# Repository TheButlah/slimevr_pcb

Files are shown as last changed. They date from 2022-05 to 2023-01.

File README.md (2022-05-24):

# slimevr_pcb
A collection of PCBs designed for SlimeVR full-body trackers

- [ferrous_slime](/hardware/ferrous_slime/) - A fully custom surface-mount PCB.
  Unlike most of the SlimeVR community, it uses the ESP32-C3, a newer and more
  powerful chip. Designed to be a more powerful development platform, as it natively
  supports JTAG debugging over USB, more compilers and languages, including Rust,
  and supports Bluetooth LE v5.0.
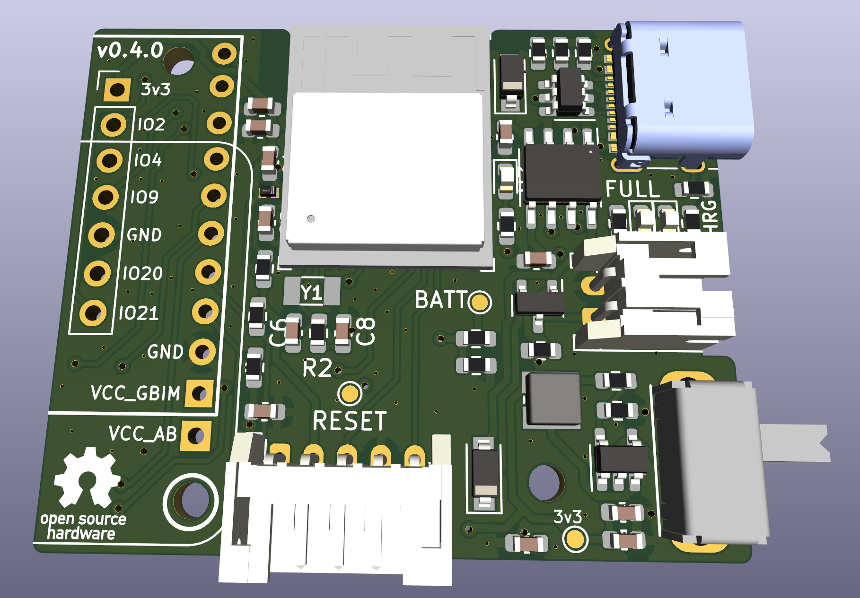
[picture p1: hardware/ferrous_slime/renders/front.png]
3d render
  
- [breakout_slime](/hardware/breakout_slime/) - A through-hole PCB for use with
  breakout boards. Simplest and easy to assemble by hand, but not as small of a
  form factor as it could be.
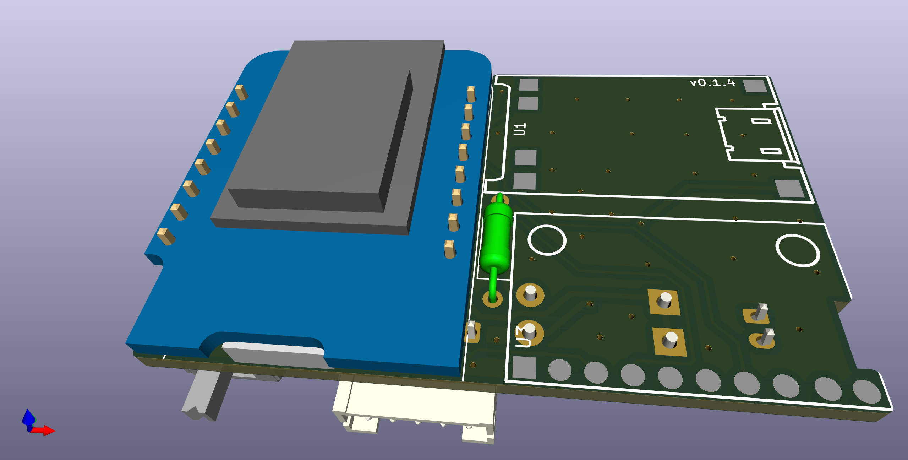
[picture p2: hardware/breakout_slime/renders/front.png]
3d render
  

## License
**This hardware is licensed under the CERN-OHL-P v2 license**, which is a permissive,
non-viral and non-reciprocal open hardware license. Unlike software licenses like
MIT and Apache 2.0, it better handles the nuances of hardware and protects both
the licensor and licensee from patent lawsuits.

**Unless you explicitly state otherwise, any contribution intentionally submitted
for inclusion in this work by you, shall be licensed as above, without any
additional terms or conditions.**

### Conveying notice of License
Note that as part of the CERN-OHL-P v2 license, recipients of manufactured
hardware must also receive notice of the above license. One such
method of conveying the notice is to include a link to the original source repo,
or printing "Licensed under CERN-OHL-P v2" on the PCB silkscreen. For more info,
see [here](https://ohwr.org/project/cernohl/wikis/uploads/8a6b5d01f71c207c49493e4d114d61e6/cern_ohl_p_v2_howto.pdf).

This is conceptually similar to the MIT/Apache 2.0 Licenses, where the original
license must still be included as a notice even when the source is modified and
subsequently relicensed under different terms.

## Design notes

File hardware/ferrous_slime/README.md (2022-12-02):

# Ferrous SlimeVR
This PCB design is intended as a production-ready (mostly) SMT design. Unlike
current SlimeVR designs by the community and the production batch that use the
ESP8266, this board uses the *very* new ESP32-C3 chip, which is better in almost
all respects than its predecessors.

The IMU is still a breakout board to better allow the community to experiment
with different IMU options.

## IMU Compatibility
This board was designed to work with the following IMU breakouts, via solder
jumpers that can reconfigure the board.
- BNO08X (Aliexpress GY-BNO08X and Adafruit BNO08X)
- MPU-6050 (Aliexpress GY-521)
- MPU-9250/6500 (Aliexpress GY-9250 and MPU-92/65)
- ICM20948 3.3v (Aliexpress GY-912 and Pimoroni PIM448)

## Renders
Front
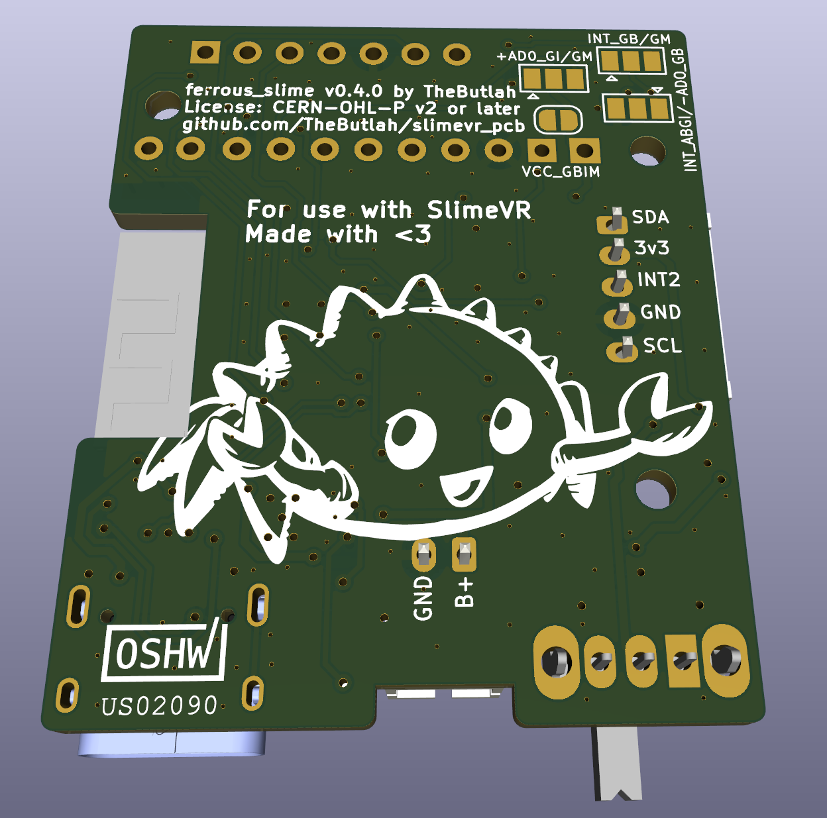
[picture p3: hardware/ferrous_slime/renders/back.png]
Back

Schematic
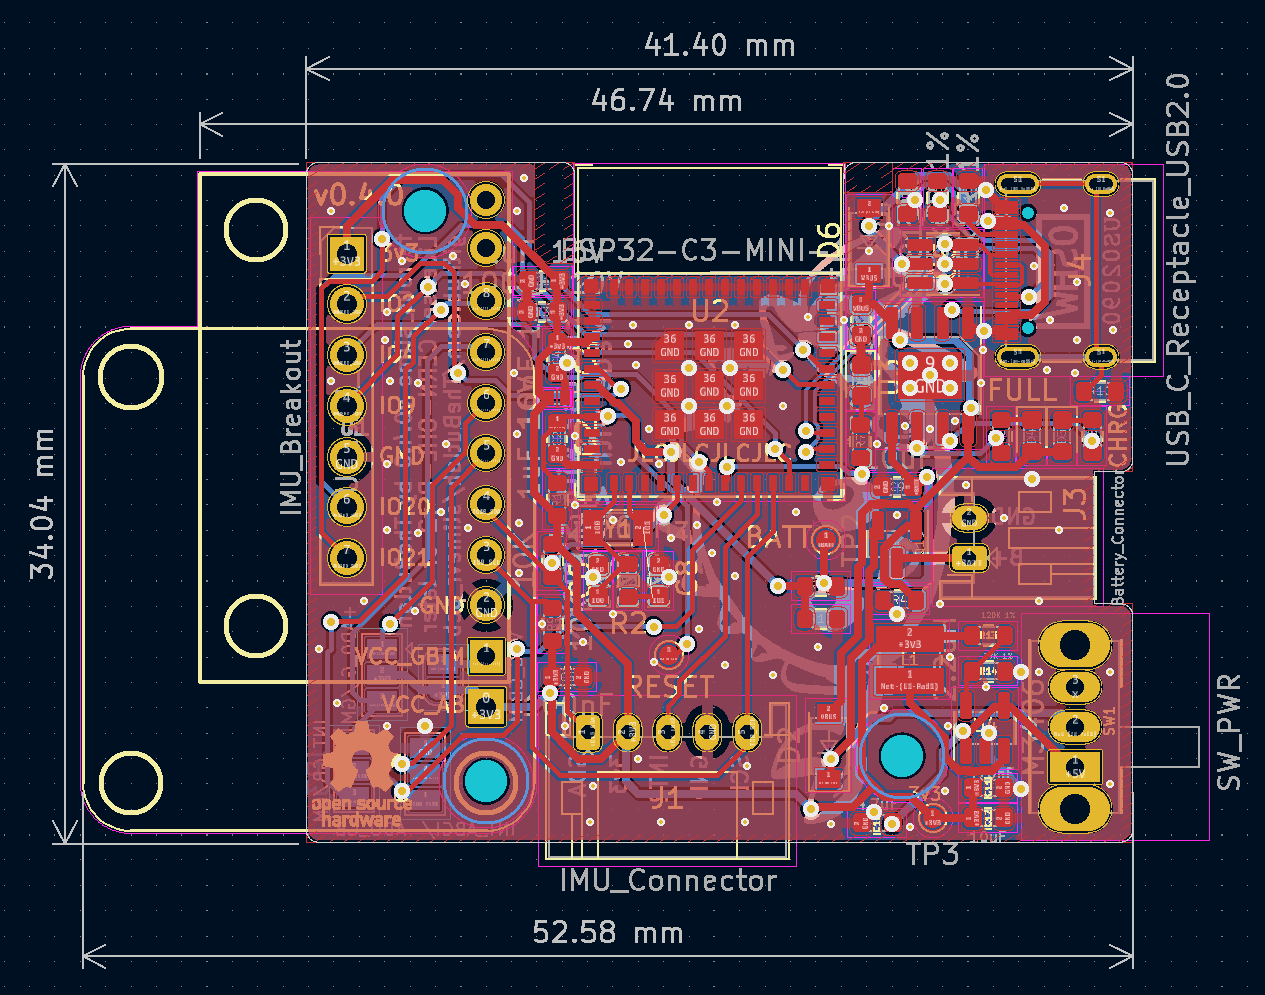
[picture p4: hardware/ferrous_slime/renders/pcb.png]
PCB


As always, check to make sure your particular breakout board has the pins in the
right spots for this PCB! Not all breakouts of the same IMU have the same pins!

## Why the ESP32-C3?
First and foremost, the ESP32-C3 uses RISC-V as its instruction set, rather than
XTensa. XTensa is not supported by LLVM (yet), or by the Rust programming language,
without using a [fork of the compiler](https://github.com/espressif/llvm-project).
I wanted to use this design in future IOT projects as well, so targeting a more
mainstream instruction set with better compiler support seems useful. It will also
help me more easily use Rust with this device!

Secondly, the ESP32-C3 is similar in features to the ESP32 series of chips, but like
the ESP8266, it is very cheap, making it a great choice. A few of the features it has
over the ESP8266:
- Bluetooth LE v5.0 (even ESP32 only has v4.2)
- Stronger WiFi signal at a lower power usage than the ESP8266
- More RAM (400KiB vs 160)
- Built-in USB-serial and USB-JTAG support eliminates need for USB-UART chip
- JTAG debugging
- Sleep modes consume *significantly* less power
- New peripherals like security modules
- GPIO is more fully featured, and has more pins

For more info, [this](https://hackaday.com/2021/02/08/hands-on-the-risc-v-esp32-c3-will-be-your-new-esp8266/)
was a good article.

## Changelog
A description of the changes in each revision can be found [here](CHANGELOG.md).

## Credits
The original v0.1.0 design was based on the schematics of the [esp-rs Rust board](https://github.com/esp-rs/esp-rust-board).
Thanks to the esp-rs community for being so awesome!
Also, thanks to the SlimeVR developers and especially @Eirenliel for making SlimeVR awesome and open source :)

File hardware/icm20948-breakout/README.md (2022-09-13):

# ICM-20948 Breakout for `ferrous_slime`
This is a breakout board for the [ICM-20948](https://invensense.tdk.com/products/motion-tracking/9-axis/icm-20948/) IMU, targeting the [`ferrous_slime` board by TheButlah](https://github.com/TheButlah/slimevr_pcb/tree/main/hardware/ferrous_slime).  It contains a voltage translator to allow 1.8v<->3.3v communication between the IMU and the ESP.

The pin socket is optional and only serves to allow rapid prototyping of the board.  Final revisions may be directly soldered to the `ferrous_slime` or attached via a double-sided pin header.

*Note: This breakout is currently being tested and may not work as intended.*

## Renders
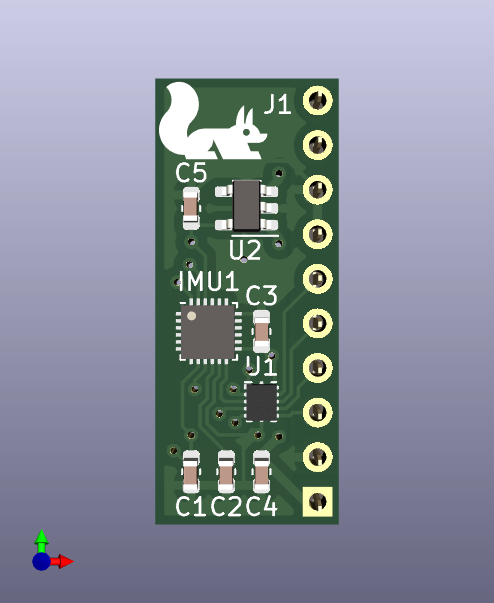
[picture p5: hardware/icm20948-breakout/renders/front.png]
Front

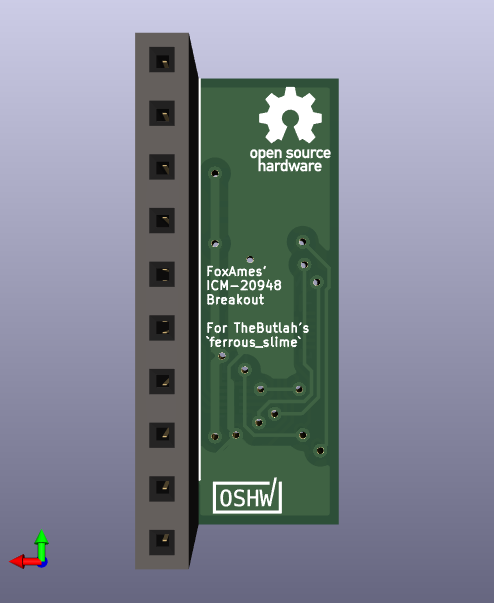
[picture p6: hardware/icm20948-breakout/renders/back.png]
Back

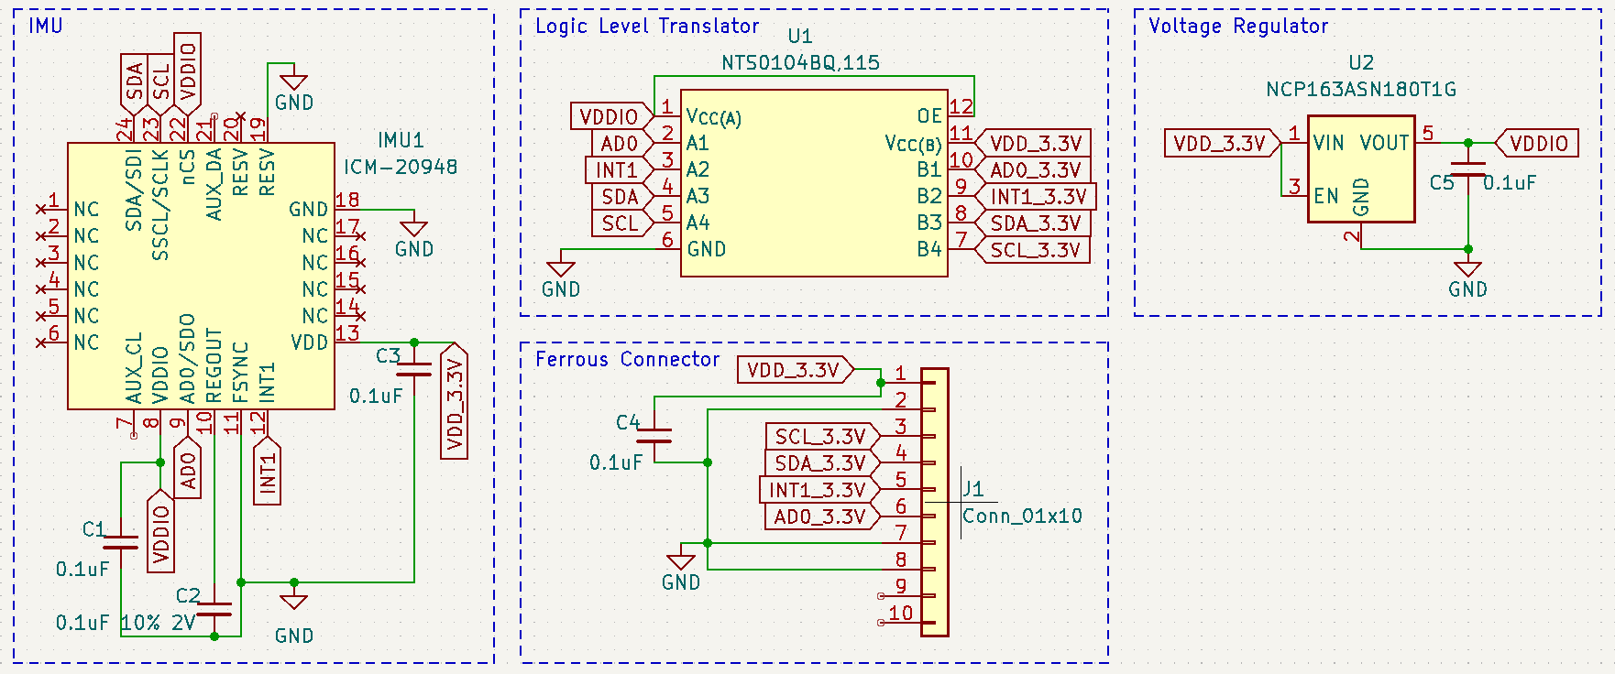
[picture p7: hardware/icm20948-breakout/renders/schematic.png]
Schematic


## Thanks
- [dtornqvist](https://github.com/dtornqvist/icm-20948-breakout) for a part list and implementation reference

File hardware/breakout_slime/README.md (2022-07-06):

# Breakout SlimeVR
This PCB design is intended as the easiest DIY SlimeVR pcb. It is a simple two
layer PCB, and should make assembling SlimeVR significantly easier than using a
protoboard.

**NOTE: This has only been tested on BNOs and MPUs.**
Also, use it at your own risk. I've tested it, but I accept no responsibility for it ;)

## Renders
Front
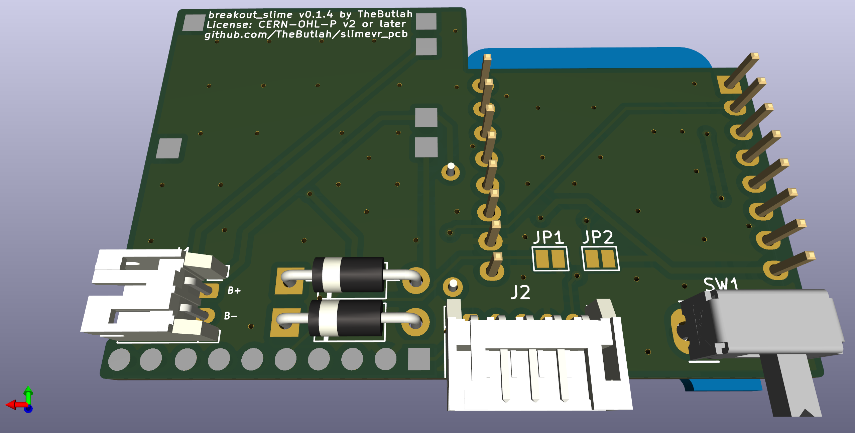
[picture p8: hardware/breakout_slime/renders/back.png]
Back

Schematic
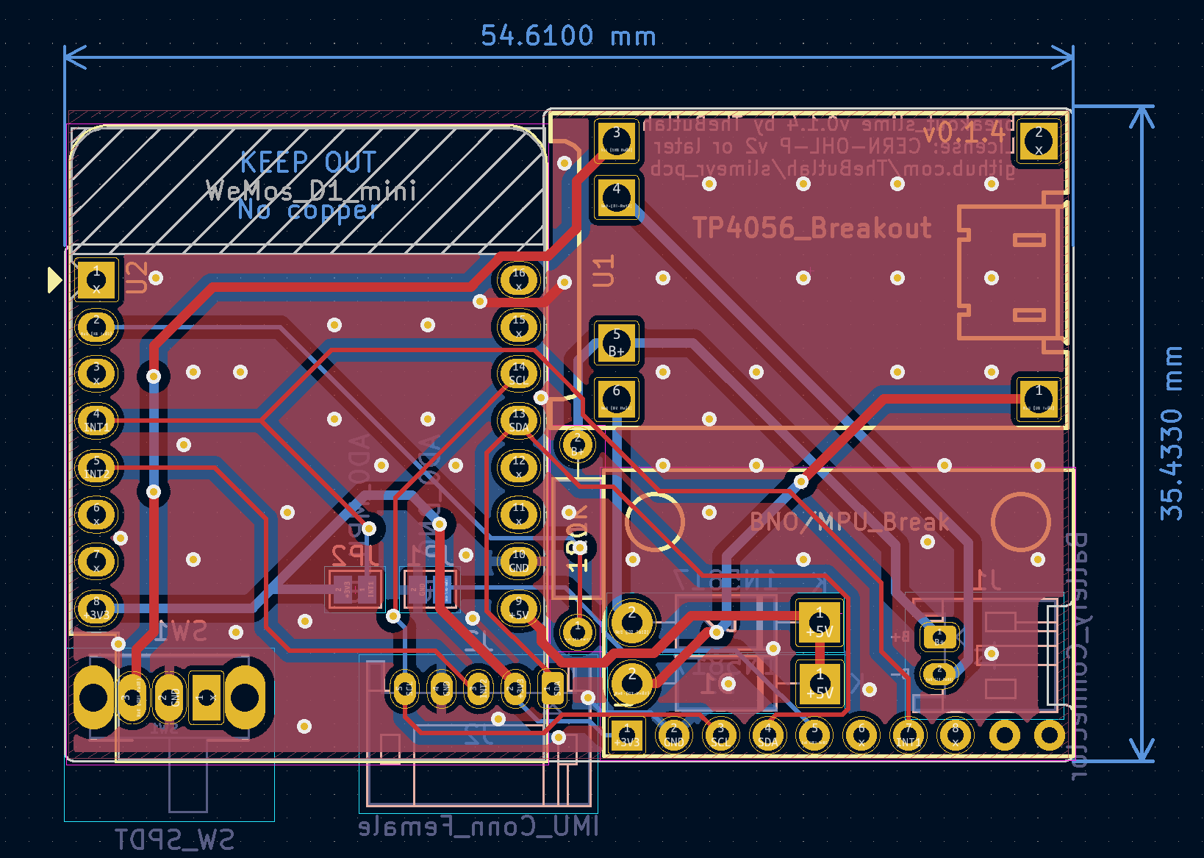
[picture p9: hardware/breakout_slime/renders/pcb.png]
PCB

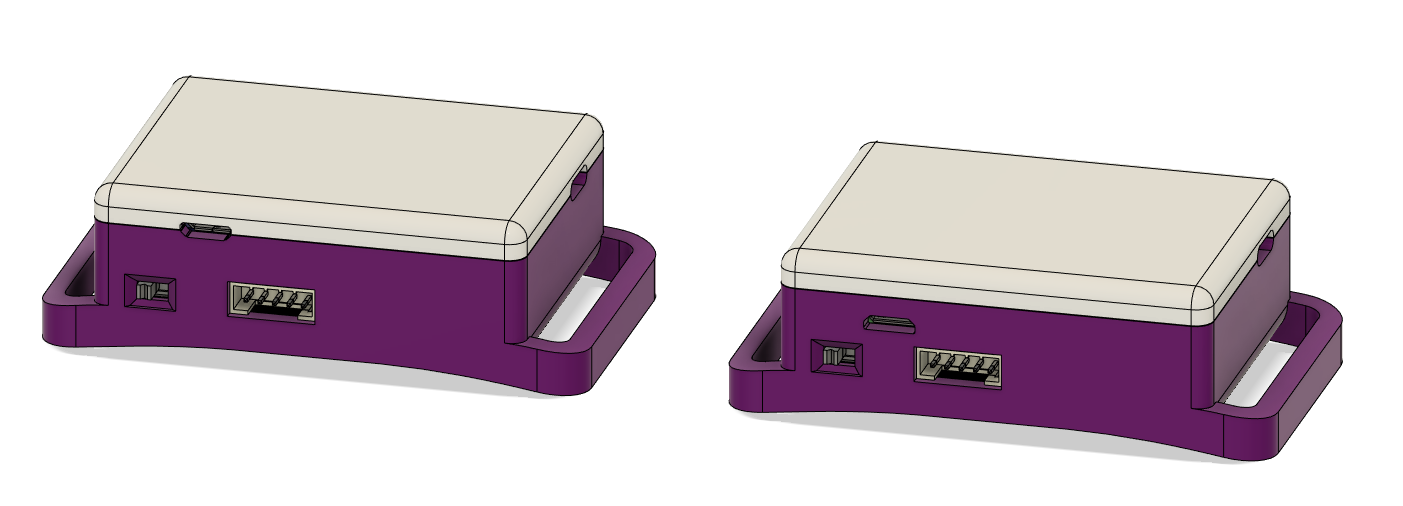
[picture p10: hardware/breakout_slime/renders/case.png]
Case


## Changelog
A description of the changes in each revision can be found [here](CHANGELOG.md).

## How to order
You can place a jlcpcb order by uploading the [zip file](jlcpcb/gerber/GERBER-breakout_slime.zip) for the gerbers. Take that zip file and upload to https://jlcpcb.com.

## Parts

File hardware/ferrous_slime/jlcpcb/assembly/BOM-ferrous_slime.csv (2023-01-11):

Comment | Designator | Footprint | LCSC
100nF 10V | C3,C5 | C_0603_1608Metric | C14663
1uF 16V | C1,C2 | C_0603_1608Metric | C15849
470nF | C11 | C_0603_1608Metric | C1623
TP4056 | U3 | HTSOP-8-1EP_3.9x4.9mm_P1.27mm_EP2.4x3.2mm | C16581
LESD8D3.3CAT5G | D1 | SOD882 | C172409
4.7uF | C10 | C_0603_1608Metric | C19666
10uF | C12,C7,C9 | C_0603_1608Metric | C19702
2.2uH | L1 | L_Wuerth_MAPI-3015 | C19734
1K | R5,R6,R7 | R_0603_1608Metric | C21190
CHRG | D3 | LED_0603_1608Metric | C2286
27K 1% | R14 | R_0603_1608Metric | C22967
2K | R3 | R_0603_1608Metric | C22975
30K 1% | R12 | R_0603_1608Metric | C22984
5k1R 1% | R15,R16 | R_0603_1608Metric | C23186
10kR 1% | R1,R8,R9 | R_0603_1608Metric | C25804
120K | R10,R11,R13,R4 | R_0603_1608Metric | C25808
ESP32-C3-MINI-1 | U2 | ESP32-C3-MINI-1 | C2838502
USB_C_Receptacle_USB2.0 | J4 | USB_C_Receptacle_XKB_U262-16XN-4BVC11 | C319148
10nF 10V | C4 | C_0603_1608Metric | C57112
LED_IO5 | D5 | LED_0603_1608Metric | C72038
FULL | D4 | LED_0603_1608Metric | C72043
M3406 | U4 | SOT-23-5 | C83224
SRV05-4 | U5 | SOT-23-6 | C85364
CJ2305 | Q1 | SOT-23 | C8549
B5819W | D2,D6 | D_SOD-123 | C8598
IMU_Connector | J1 | JST_PH_S5B-PH-K_1x05_P2.00mm_Horizontal
3v3 | TP3 | TestPoint_Pad_D1.0mm
Battery_Connector | J3 | JST_PH_S2B-PH-K_1x02_P2.00mm_Horizontal
SW_PWR | SW1 | SW_CuK_OS102011MA1QN1_SPDT_Angled
+AD0_GI/GM | JP1 | SolderJumper-3_P1.3mm_Open_Pad1.0x1.5mm
IMU_Breakout | U1 | IMU_Breakout
BATT | TP2 | TestPoint_Pad_D1.0mm
INT_GB/GM | JP3 | SolderJumper-3_P1.3mm_Open_Pad1.0x1.5mm
INT_ABGI/-ADO_GB | JP2 | SolderJumper-3_P1.3mm_Open_Pad1.0x1.5mm
DNP | R2 | R_0603_1608Metric
Unused_IO | J2 | IO_Breakouts
VCC_GBIM | JP4 | SolderJumper-2_P1.3mm_Open_RoundedPad1.0x1.5mm
RESET | TP1 | TestPoint_Pad_D1.0mm

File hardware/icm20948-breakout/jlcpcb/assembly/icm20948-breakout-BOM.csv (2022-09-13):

Comment | Designator | Footprint
NCP163ASN180T1G | U2 | SOT-23-5
0.1uF 10% 2V | C2 | C_0603_1608Metric
0.1uF | C5,C4,C1,C3 | C_0603_1608Metric
NTS0104BQ,115 | U1 | XQFN12
ICM-20948 | IMU1 | QFN-24-1EP_3x3mm_P0.4mm_EP1.75x1.6mm
Conn_01x10 | J1 | PinSocket_1x10_P2.54mm_Vertical

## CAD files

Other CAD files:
hardware/breakout_slime/case/Butter_Dish.3mf
hardware/breakout_slime/case/breakout_slime.3mf
hardware/breakout_slime/case/Butter_Dish_Fusion360.f3z
hardware/breakout_slime/case/breakout_slime.f3z

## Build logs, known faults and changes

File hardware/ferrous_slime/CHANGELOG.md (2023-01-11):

# Changelog

## v0.1.0
- Initial version of the board.
- Ordered PCB to test.

## v0.2.0
- Added 3 mounting holes.
- Added support for Adafruit BNO085.
- Improved legibility of silkscreen labels.
- Decreased sharpness of corners.
- Added support for soldering IMU breakouts flush with PCB.
- Fixed rendering of imu breakout pins.

## v0.3.0
- **Switched battery polarity** to match adafruit batteries.
- Moved silkscreen for "FULL" LED.
- Made measurement markings in mm with 2 digits of precision.
- PROG pin on TP4056 was incorrectly connected to VBUS, preventing LiPo charging.
  It is now fixed.
- Simplified name of IMU_Breakout.
- Satisfied ERC for VCC pin of aliexpress imus.
- Fixed footprint/symbols not referencing each other correctly for IMU.
- Added silkscreen labels for IMU breakout pins
- Connected TP4056 heatsink to GND

## v0.4.0
- Migrated to SRV05-04 for USB ESD, decreasing size and cost.
- Completely redesigned the board layout. Its much more efficient now, there is
  actually a large amount of unused space now.
- Removed all vias-in-pads, which was why v0.3.0 had faulty usb connection.
- Much better placement of capacitors, they now are near the pins they try to stabilize. 
- Antennas now have some keepouts on either side for a bit more signal strength.

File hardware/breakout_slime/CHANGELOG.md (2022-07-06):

# Changelog

## v0.1
- Ordered PCB to test. Tests confirmed that pcb works for MPU, but battery
  polarity reversed, and INT1 pin goes to wrong pad which breaks BNO unless INT pin
  disabled in firmware. Battery polarity was also reversed, requiring installing
  the connector in reverse.

## v0.1.1
- Filled back ground pour.
- Fixed battery polarity on JST battery connector.
- Fixed INT1 wiring.

## v0.1.2
- Added a front ground pour, and optimized the two ground pours.
- Added edge cut on D1 antenna region.
- Added keepout on d1 antenna region.
- Added edge cut on battery connector.
- Added revision number to silkscreen.

## v0.1.3
- Changed D1 mini model to not use super tall headers in 3d view.
- Added B+ and B- to silkscreen.
- Rounded out corners of edge cuts.
- Re-reversed the battery polarity. It now has B+ on pin 1 of the JST connector. This
  matches adafruit and sparkfun conventions, and also the batteries I ordered on
  aliexpress. Not all batteries follow this convention!
- Removed the redundant keepout region on antenna, since its got edge cuts now.
- Assigned the rest of the power nets to the power netclass.
- Redid the old nets to use the thicker power netclass thickness.
- Now using same switch 3d model as `ferrous_slime`.

## v0.1.4
- Moved Power switch and IMU Connector further apart to decrease the likelihood of
  collision with a D1 mini's USB connector, if that D1 mini has the connector on the
  underside of its board.

## v0.1.5
- Added Case by @TomYumVR

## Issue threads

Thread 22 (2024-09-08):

I created a case for your PCB

Gammelstulle, 2024-09-08:
Hi :)
I liked your compact design of the PCB but the case you included was not compact enough for me.
So I made one:

https://www.thingiverse.com/thing:6759053

Hope you like it. If there is something I should included in the description at thingiverse please let me know.

TheButlah, 2024-09-09:
Super awesome! Want me to link it in the README?

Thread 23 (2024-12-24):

Question on breakout jps

timbit123, 2024-12-24:
I'm trying to flash the wimos with BNO085 (slimevr one) I soldered the jp1 and jp2 and still cannot get any values on all board. I'm not sure what I'm doing wrong? thx

TheButlah, 2024-12-24:
Hey sorry, there's not enough info to help u here. Also it's been a long time so my memory is rusty. Best to ask others in the slimevr discord. You can show them the schematics from this repo

timbit123, 2024-12-24:
ok thanks, I will ask @Gammelstulle, I think he have the same configuration as me

Closed 2024-12-24.

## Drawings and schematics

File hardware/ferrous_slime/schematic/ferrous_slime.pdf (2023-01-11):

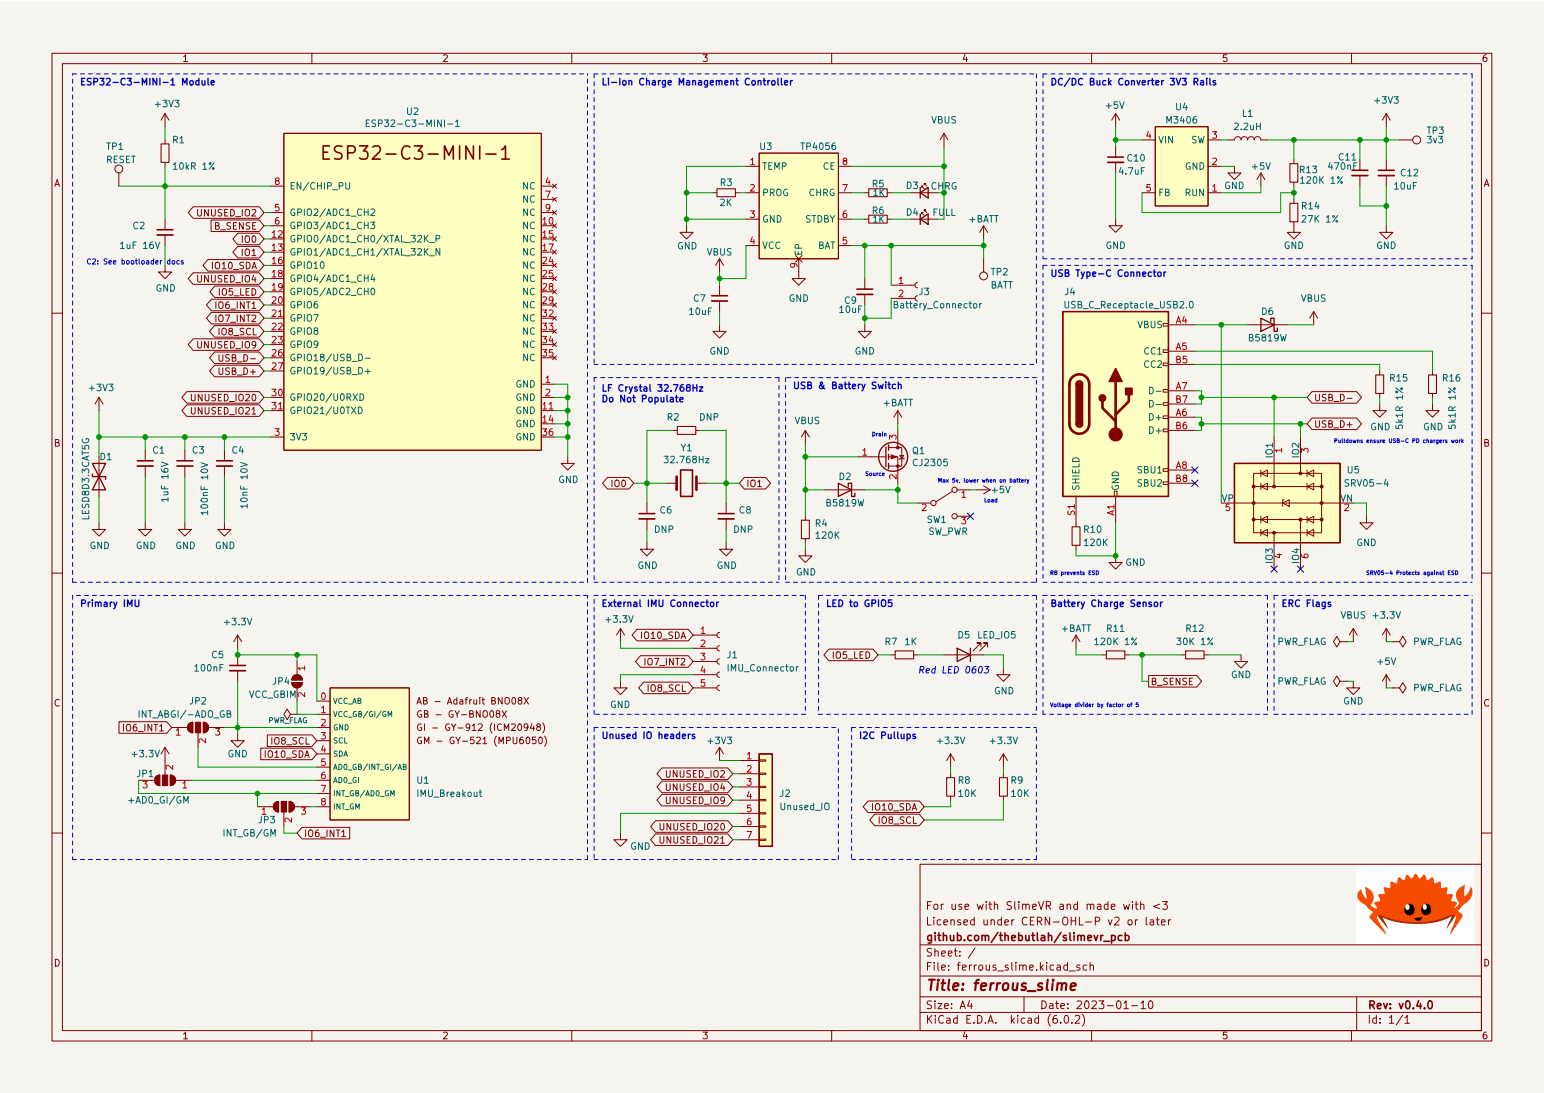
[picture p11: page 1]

DC/DC Buck Converter 3V3 Rails

Pulldowns ensure USB-C PD chargers work LF Crystal 32.768Hz
Do Not Populate

Drain Source USB & Battery Switch

R8 prevents ESD Max 5v, lower when on battery Primary IMU

Load External IMU Connector

Voltage divider by factor of 5 Battery Charge Sensor

AB - Adafruit BNO08X GB - GY-BNO08X GI - GY-912 (ICM20948)

Licensed under CERN-OHL-P v2 or later For use with SlimeVR and made with <3

File: ferrous_slime.kicad_sch Sheet: / github.com/thebutlah/slimevr_pcb

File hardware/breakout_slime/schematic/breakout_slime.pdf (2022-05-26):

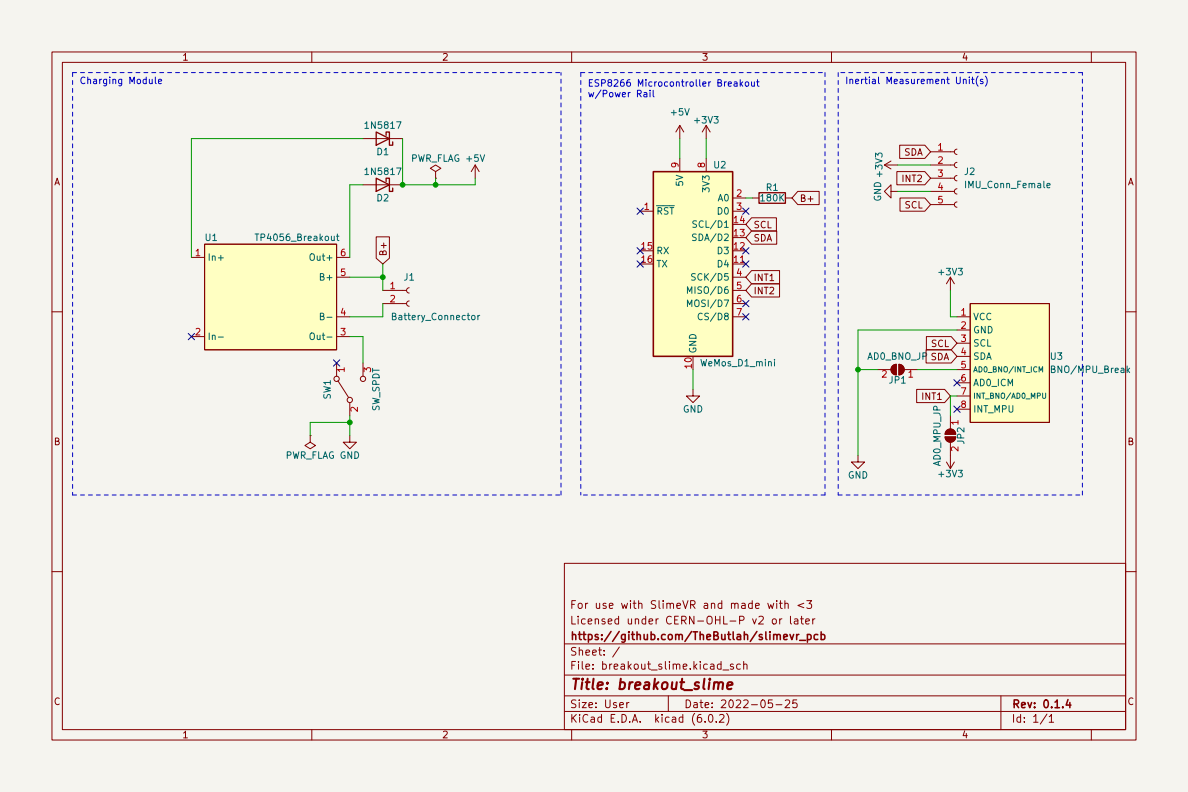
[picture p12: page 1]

File: breakout_slime.kicad_sch Sheet: / https://github.com/TheButlah/slimevr_pcb

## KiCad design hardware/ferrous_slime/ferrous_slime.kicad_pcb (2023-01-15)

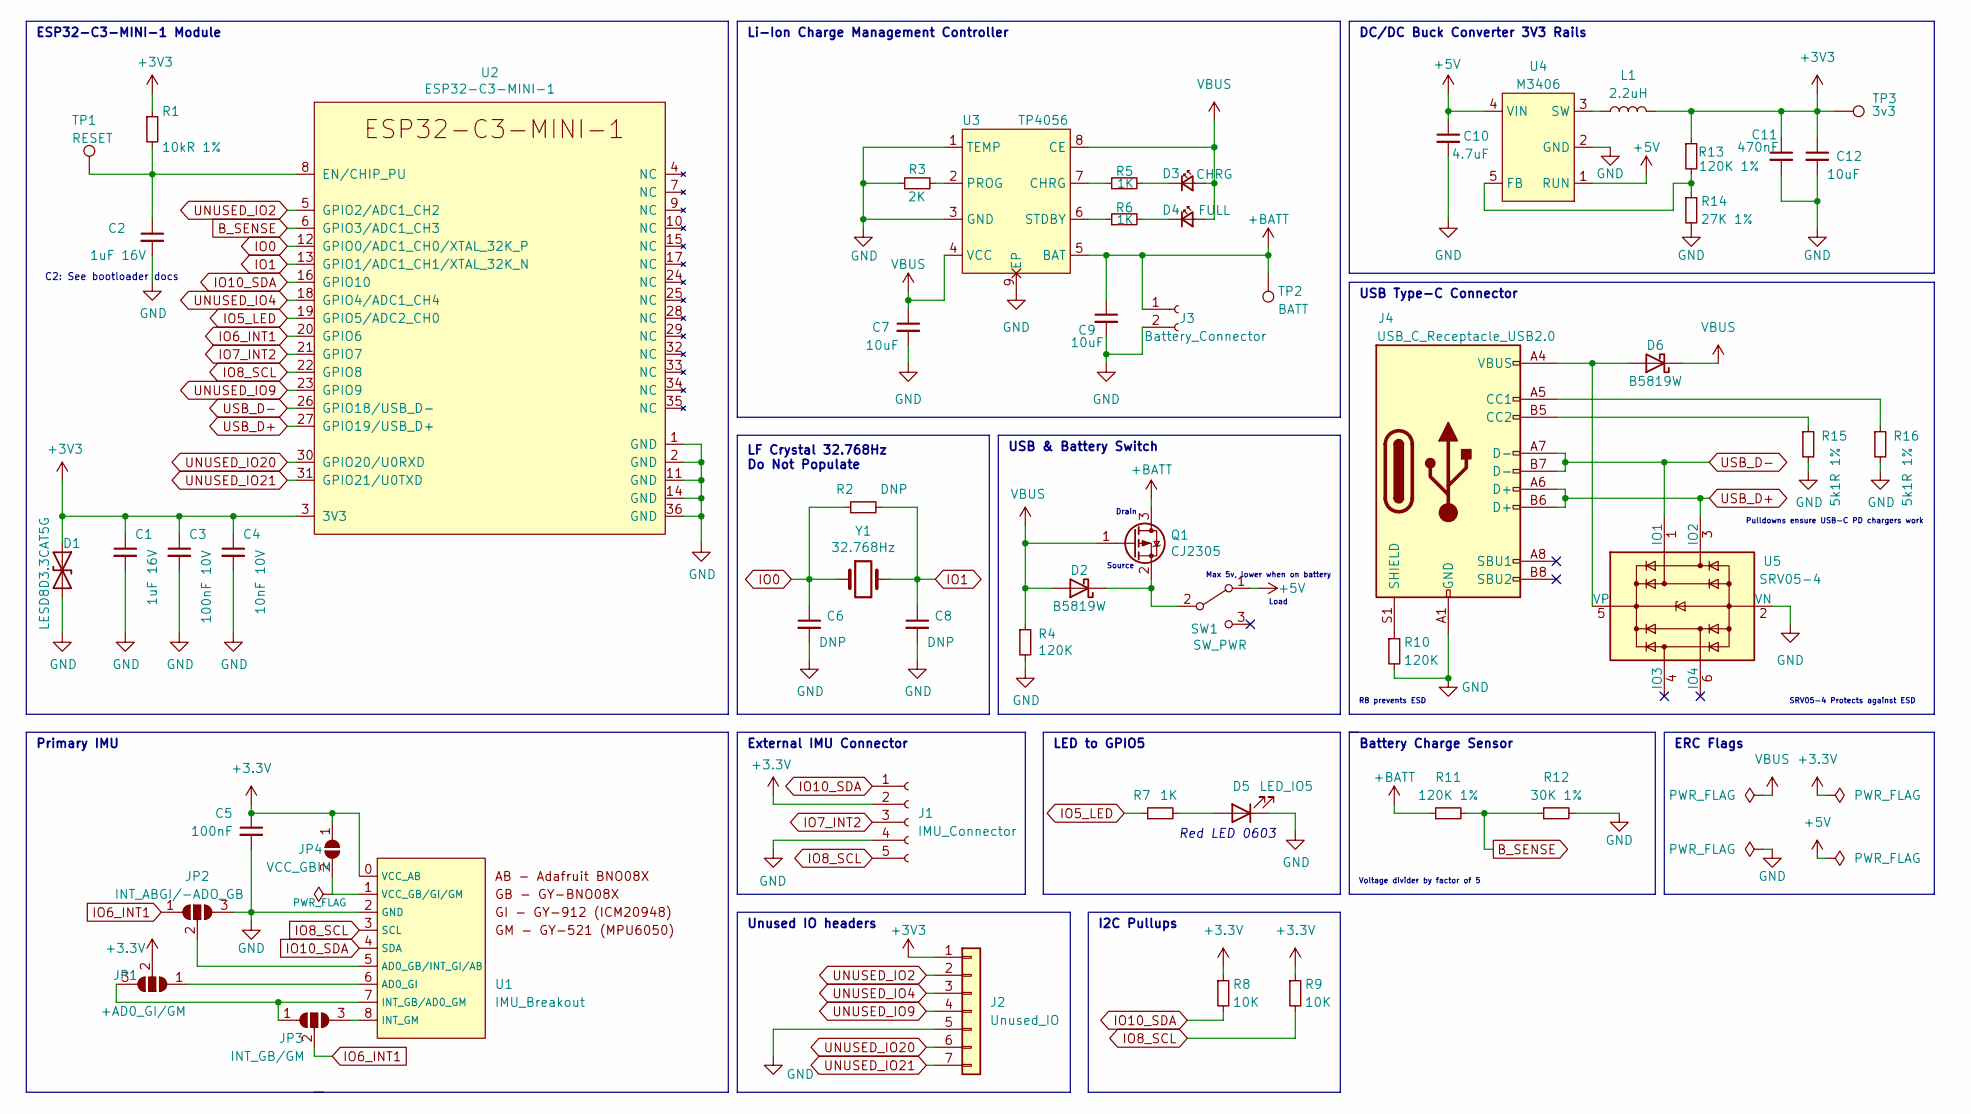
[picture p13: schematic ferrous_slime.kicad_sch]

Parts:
C1, C2: 1uF 16V; C_0603_1608Metric
C3: 100nF 10V; C_0603_1608Metric
C4: 10nF 10V; C_0603_1608Metric
C5: 100nF; C_0603_1608Metric
C6, C8: DNP; C_0603_1608Metric
C7, C9, C12: 10uF; C_0603_1608Metric
C10: 4.7uF; C_0603_1608Metric
C11: 470nF; C_0603_1608Metric
D1: LESD8D3.3CAT5G; SOD882
D2, D6: B5819W; D_SOD-123
D3: CHRG; LED_0603_1608Metric
D4: FULL; LED_0603_1608Metric
D5: LED_IO5; LED_0603_1608Metric
J1: IMU_Connector; JST_PH_S5B-PH-K_1x05_P2.00mm_Horizontal
J2: Unused_IO; IO_Breakouts
J3: Battery_Connector; JST_PH_S2B-PH-K_1x02_P2.00mm_Horizontal
J4: USB_C_Receptacle_USB2.0; USB_C_Receptacle_XKB_U262-16XN-4BVC11; PARTREV A3
JP1: +AD0_GI/GM; SolderJumper-3_P1.3mm_Open_Pad1.0x1.5mm
JP2: INT_ABGI/-ADO_GB; SolderJumper-3_P1.3mm_Open_Pad1.0x1.5mm
JP3: INT_GB/GM; SolderJumper-3_P1.3mm_Open_Pad1.0x1.5mm
JP4: VCC_GBIM; SolderJumper-2_P1.3mm_Open_RoundedPad1.0x1.5mm
L1: 2.2uH; L_Wuerth_MAPI-3015
Q1: CJ2305; SOT-23
R1: 10kR 1%; R_0603_1608Metric
R2: DNP; R_0603_1608Metric
R3: 2K; R_0603_1608Metric
R4, R10: 120K; R_0603_1608Metric
R5, R6, R7: 1K; R_0603_1608Metric
R8, R9: 10K; R_0603_1608Metric
R11, R13: 120K 1%; R_0603_1608Metric
R12: 30K 1%; R_0603_1608Metric
R14: 27K 1%; R_0603_1608Metric
R15, R16: 5k1R 1%; R_0603_1608Metric
SW1: SW_PWR; SW_CuK_OS102011MA1QN1_SPDT_Angled
TP1: RESET; TestPoint_Pad_D1.0mm
TP2: BATT; TestPoint_Pad_D1.0mm
TP3: 3v3; TestPoint_Pad_D1.0mm
U1: IMU_Breakout
U2: ESP32-C3-MINI-1
U3: TP4056; HTSOP-8-1EP_3.9x4.9mm_P1.27mm_EP2.4x3.2mm
U4: M3406; SOT-23-5
U5: SRV05-4; SOT-23-6
Y1: 32.768Hz; Crystal_SMD_3215-2Pin_3.2x1.5mm

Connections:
+5V: C10.1, SW1.1 (A), U4.1 (RUN), U4.4 (VIN)
+BATT: C9.1, J3.1, Q1.3 (D), R11.1, TP2.1, U3.5 (BAT)
B_SENSE: R11.2, R12.1, U2.6 (GPIO3/ADC1_CH3)
GND: C1.2, C2.2, C3.2, C4.2, C5.2, C6.2, C7.2, C8.2, C9.2, C10.2, C11.2, C12.2, D1.2 (A2), D5.1 (K), J1.4, J2.5, J3.2, J4.A1 (GND), J4.A12 (GND), J4.B1 (GND), J4.B12 (GND), JP2.3 (B), R3.1, R4.2, R10.2, R12.2, R14.2, R15.2, R16.2, U1.2 (GND), U2.1 (GND), U2.2 (GND), U2.11 (GND), U2.14 (GND), U2.36 (GND), U3.1 (TEMP), U3.3 (GND), U3.9 (EP), U4.2 (GND), U5.2 (VN)
IO0: C6.1, R2.1, U2.12 (GPIO0/ADC1_CH0/XTAL_32K_P), Y1.1
IO1: C8.1, R2.2, U2.13 (GPIO1/ADC1_CH1/XTAL_32K_N), Y1.2
IO5_LED: R7.1, U2.19 (GPIO5/ADC2_CH0)
IO6_INT1: JP2.1 (A), JP3.2 (C), U2.20 (GPIO6)
IO7_INT2: J1.3, U2.21 (GPIO7)
IO8_SCL: J1.5, R9.2, U1.3 (SCL), U2.22 (GPIO8)
IO10_SDA: J1.1, R8.2, U1.4 (SDA), U2.16 (GPIO10)
unnamed: C2.1, R1.2, TP1.1, U2.8 (EN/CHIP_PU)
unnamed: D2.1 (K), Q1.2 (S), SW1.2 (B)
unnamed: D3.1 (K), R5.2
unnamed: D4.1 (K), R6.2
unnamed: D5.2 (A), R7.2
unnamed: D6.2 (A), J4.A4 (VBUS), J4.A9 (VBUS), J4.B4 (VBUS), J4.B9 (VBUS), U5.5 (VP)
unnamed: J4.A5 (CC1), R16.1
unnamed: J4.B5 (CC2), R15.1
unnamed: J4.S1 (SHIELD), R10.1
unnamed: JP1.1 (A), U1.6 (AD0_GI)
unnamed: JP1.3 (B), JP3.1 (A), U1.7 (INT_GB/AD0_GM)
unnamed: JP2.2 (C), U1.5 (AD0_GB/INT_GI/AB)
unnamed: JP3.3 (B), U1.8 (INT_GM)
unnamed: JP4.2 (B), U1.1 (VCC_GB/GI/GM)
unnamed: L1.1, U4.3 (SW)
unnamed: R3.2, U3.2 (PROG)
unnamed: R5.1, U3.7 (CHRG)
unnamed: R6.1, U3.6 (STDBY)
unnamed: R13.2, R14.1, U4.5 (FB)
UNUSED_IO2: J2.2, U2.5 (GPIO2/ADC1_CH2)
UNUSED_IO4: J2.3, U2.18 (GPIO4/ADC1_CH4)
UNUSED_IO9: J2.4, U2.23 (GPIO9)
UNUSED_IO20: J2.6, U2.30 (GPIO20/U0RXD)
UNUSED_IO21: J2.7, U2.31 (GPIO21/U0TXD)
USB_D+: J4.A6 (D+), J4.B6 (D+), U2.27 (GPIO19/USB_D+), U5.3 (IO2)
USB_D-: J4.A7 (D-), J4.B7 (D-), U2.26 (GPIO18/USB_D-), U5.1 (IO1)
VBUS: C7.1, D2.2 (A), D3.2 (A), D4.2 (A), D6.1 (K), Q1.1 (G), R4.1, U3.4 (VCC), U3.8 (CE)

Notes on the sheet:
Voltage divider by factor of 5
USB Type-C Connector
Max 5v, lower when on battery
Drain
ERC Flags
LF Crystal 32.768Hz Do Not Populate
External IMU Connector
Source
DC/DC Buck Converter 3V3 Rails
Red LED 0603
USB & Battery Switch
R8 prevents ESD
Battery Charge Sensor
LED to GPIO5
Load
SRV05-4 Protects against ESD
Unused IO headers
Primary IMU
ESP32-C3-MINI-1 Module
Li-Ion Charge Management Controller
Pulldowns ensure USB-C PD chargers work
I2C Pullups
C2: See bootloader docs

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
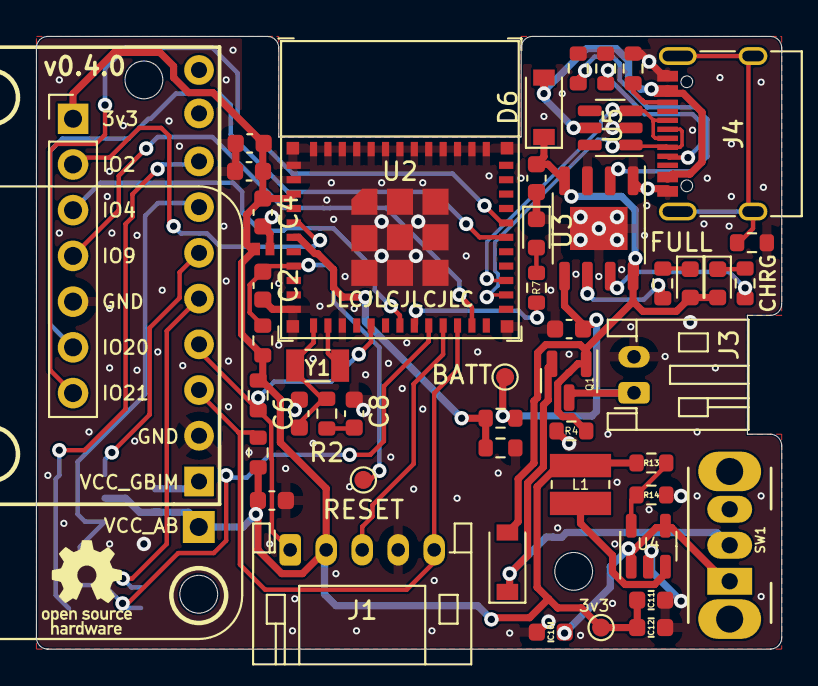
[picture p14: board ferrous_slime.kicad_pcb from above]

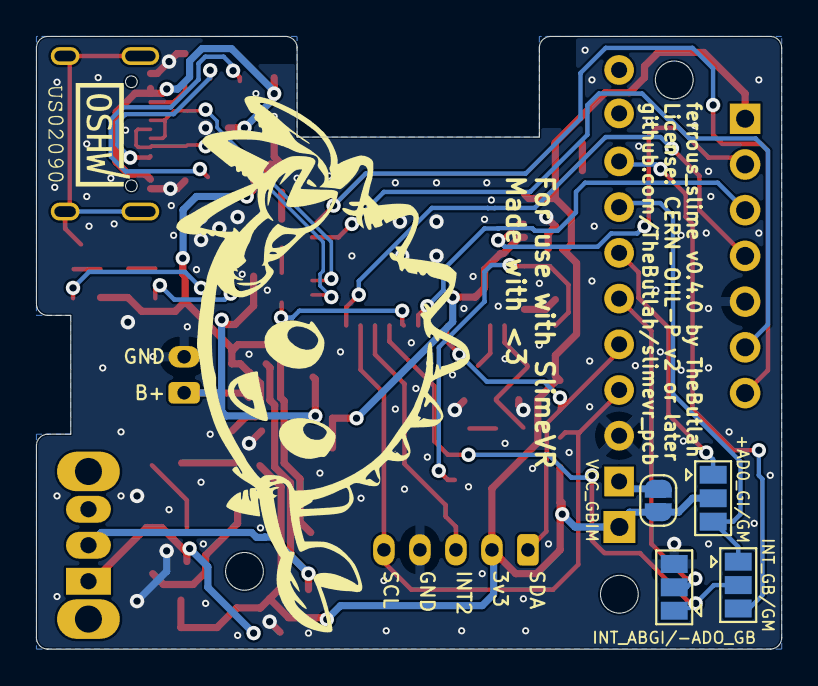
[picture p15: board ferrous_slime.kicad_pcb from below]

Board: 2 copper layers, 41.4 x 34.0 mm, 57 parts (4 on the bottom side), 39 nets.

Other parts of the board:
H1, H2, H3: MountingHole_2.1mm

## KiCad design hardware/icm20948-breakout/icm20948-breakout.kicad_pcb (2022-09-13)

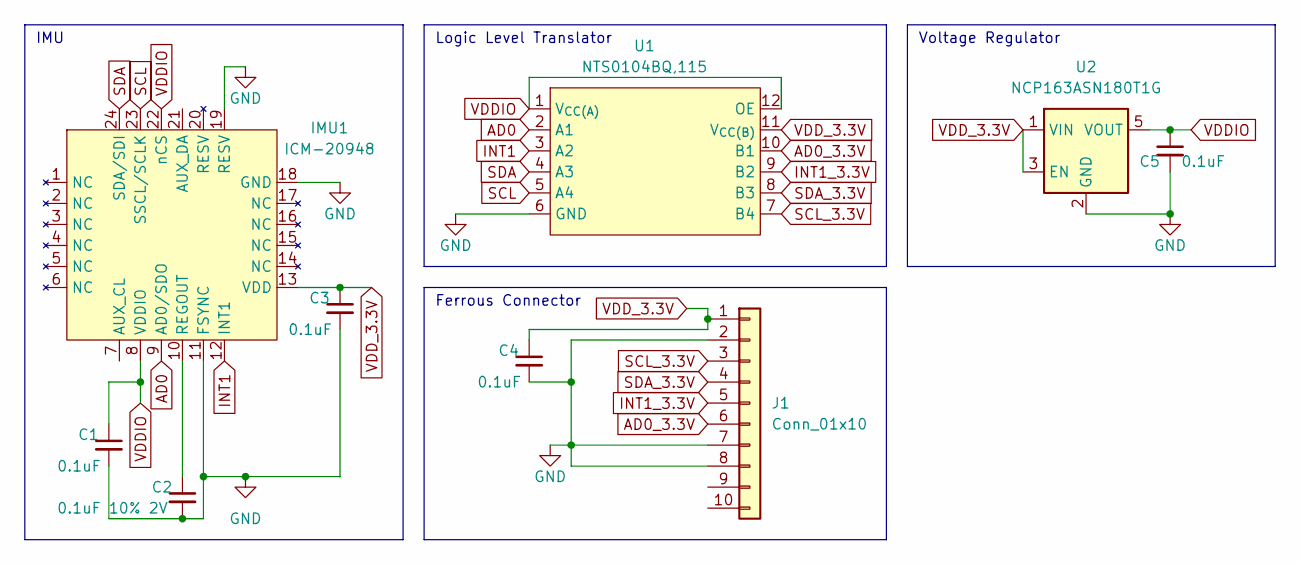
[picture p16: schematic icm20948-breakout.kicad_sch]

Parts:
C1, C3, C4, C5: 0.1uF; C_0603_1608Metric
C2: 0.1uF 10% 2V; C_0603_1608Metric
IMU1: ICM-20948; QFN-24-1EP_3x3mm_P0.4mm_EP1.75x1.6mm
J1: Conn_01x10; PinSocket_1x10_P2.54mm_Vertical
U1: NTS0104BQ,115; XQFN12
U2: NCP163ASN180T1G; SOT-23-5

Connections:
AD0: IMU1.9 (AD0/SDO), U1.2 (A1)
AD0_3.3V: J1.6, U1.10 (B1)
GND: C1.2, C2.2, C3.2, C4.2, C5.2, IMU1.11 (FSYNC), IMU1.18 (GND), IMU1.19 (RESV), J1.2, J1.7, J1.8, U1.6 (GND), U2.2 (GND)
INT1: IMU1.12 (INT1), U1.3 (A2)
INT1_3.3V: J1.5, U1.9 (B2)
unnamed: C2.1, IMU1.10 (REGOUT)
SCL: IMU1.23 (SSCL/SCLK), U1.5 (A4)
SCL_3.3V: J1.3, U1.7 (B4)
SDA: IMU1.24 (SDA/SDI), U1.4 (A3)
SDA_3.3V: J1.4, U1.8 (B3)
VDDIO: C1.1, C5.1, IMU1.8 (VDDIO), IMU1.22 (nCS), U1.1 (V_{CC(A)}), U1.12 (OE), U2.5 (VOUT)
VDD_3.3V: C3.1, C4.1, IMU1.13 (VDD), J1.1, U1.11 (V_{CC(B)}), U2.1 (VIN), U2.3 (EN)

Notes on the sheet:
Voltage Regulator
IMU
Ferrous Connector
Logic Level Translator

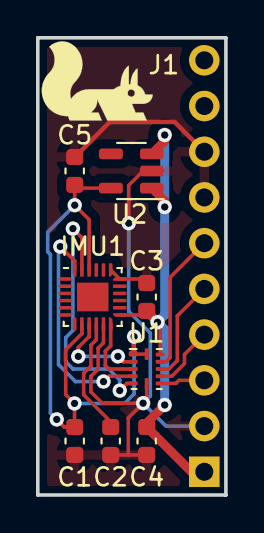
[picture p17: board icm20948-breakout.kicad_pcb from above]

Board: 2 copper layers, 10.5 x 25.4 mm, 9 parts (1 on the bottom side), 12 nets.

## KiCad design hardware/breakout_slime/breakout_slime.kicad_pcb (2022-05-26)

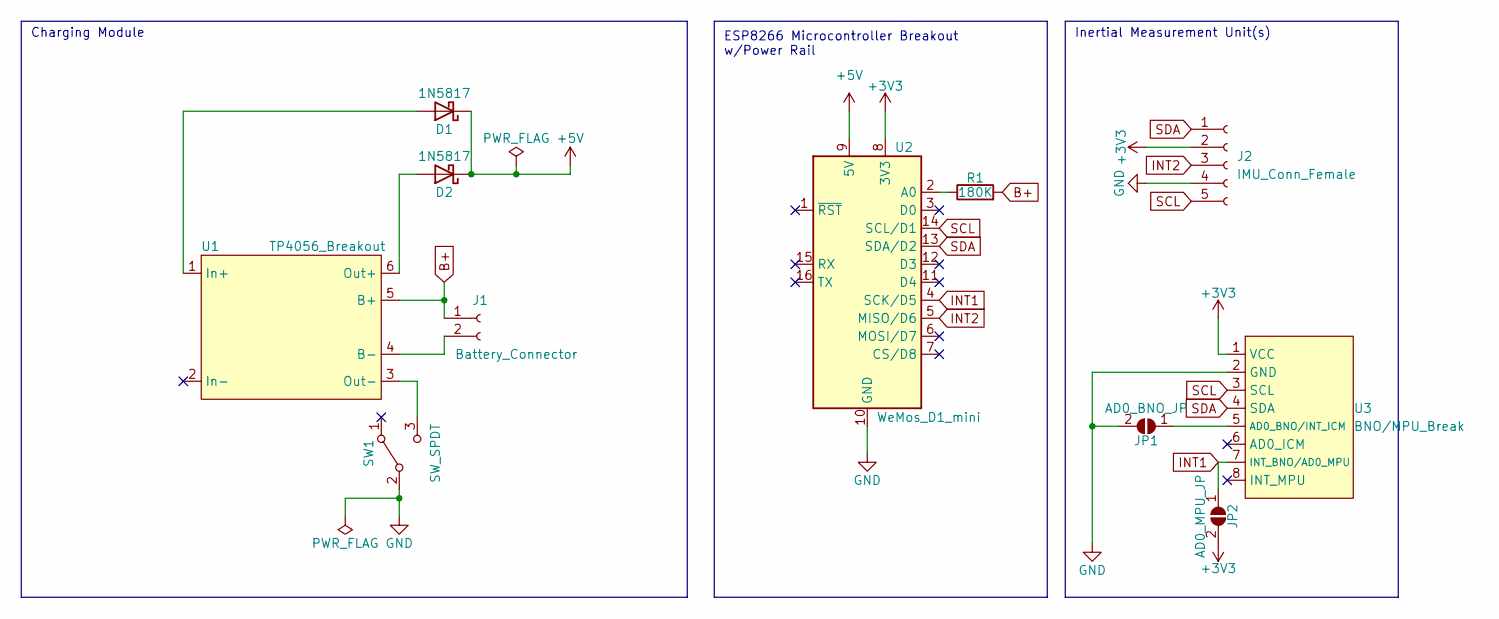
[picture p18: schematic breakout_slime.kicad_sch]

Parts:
D1, D2: 1N5817; D_DO-41_SOD81_P10.16mm_Horizontal
J1: Battery_Connector; JST_PH_S2B-PH-K_1x02_P2.00mm_Horizontal
J2: IMU_Conn_Female; JST_PH_S5B-PH-K_1x05_P2.00mm_Horizontal
JP1: AD0_BNO_JP; SolderJumper-2_P1.3mm_Open_Pad1.0x1.5mm
JP2: AD0_MPU_JP; SolderJumper-2_P1.3mm_Open_Pad1.0x1.5mm
R1: 180K; R_Axial_DIN0207_L6.3mm_D2.5mm_P10.16mm_Horizontal
SW1: SW_SPDT; SW_CuK_OS102011MA1QN1_SPDT_Angled
U1: TP4056_Breakout
U2: WeMos_D1_mini; WEMOS_D1_mini_light
U3: BNO/MPU_Break; BNO_MPU_ICM_Breakout

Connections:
+3V3: J2.2, JP2.2 (B), U2.8 (3V3), U3.1 (VCC)
+5V: D1.1 (K), D2.1 (K), U2.9 (5V)
B+: J1.1, R1.2, U1.5 (B+)
GND: J2.4, JP1.2 (B), SW1.2 (B), U2.10 (GND), U3.2 (GND)
INT1: JP2.1 (A), U2.4 (SCK/D5), U3.7 (INT_BNO/AD0_MPU)
INT2: J2.3, U2.5 (MISO/D6)
unnamed: D1.2 (A), U1.1 (In+)
unnamed: D2.2 (A), U1.6 (Out+)
unnamed: J1.2, U1.4 (B-)
unnamed: JP1.1 (A), U3.5 (AD0_BNO/INT_ICM)
unnamed: R1.1, U2.2 (A0)
unnamed: SW1.3 (C), U1.3 (Out-)
SCL: J2.5, U2.14 (SCL/D1), U3.3 (SCL)
SDA: J2.1, U2.13 (SDA/D2), U3.4 (SDA)

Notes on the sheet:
Charging Module
ESP8266 Microcontroller Breakout w/Power Rail
Inertial Measurement Unit(s)

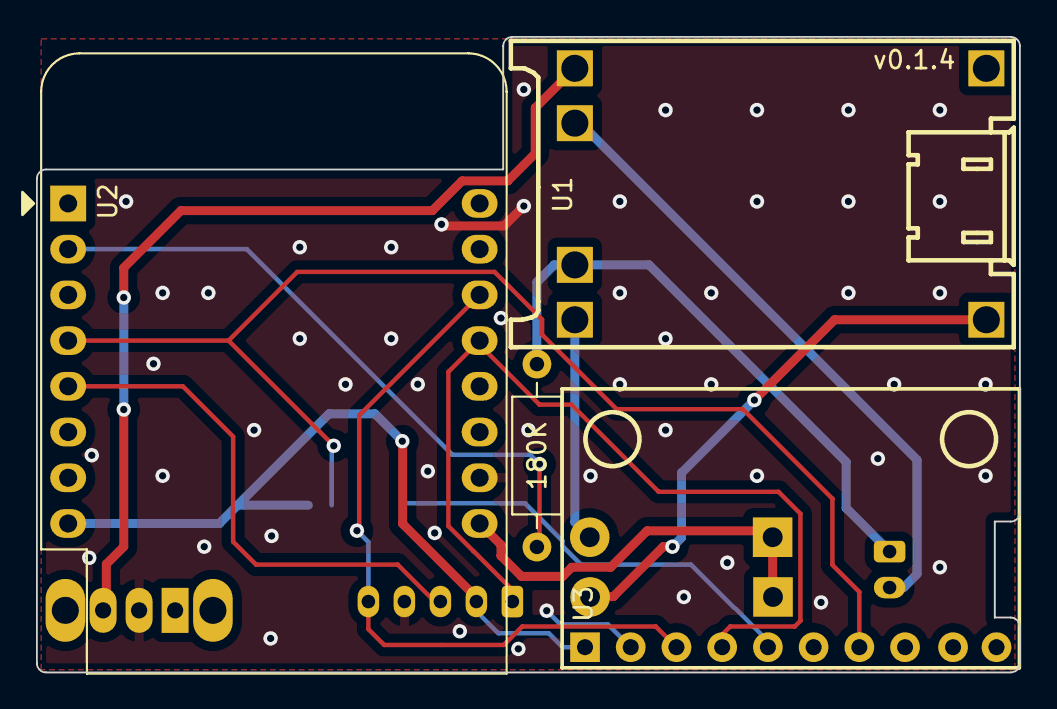
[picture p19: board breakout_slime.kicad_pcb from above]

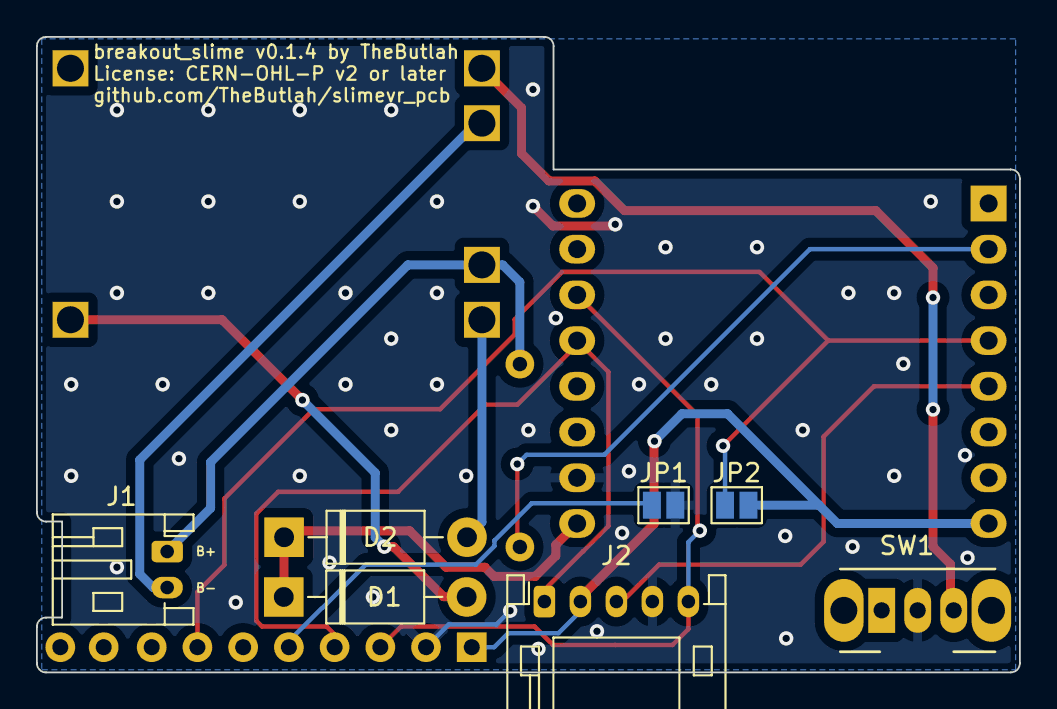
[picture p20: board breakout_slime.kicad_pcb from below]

Board: 2 copper layers, 54.6 x 35.3 mm, 11 parts (7 on the bottom side), 14 nets.

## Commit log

2022-02-24 Finished schematic
    [breakout_slime.kicad_pcb, breakout_slime.kicad_sch]
2022-02-24 Assigned Footprints
    [breakout_slime.kicad_sch]
2022-02-27 Added TP4056 breakout and assigned more footprints
    [breakout_slime.kicad_sch]
2022-02-27 Added BNO_MPU_Breakout
    [breakout_slime.kicad_sch]
2022-02-27 Added comment about the status of the board
    [breakout_slime.kicad_pcb]
2022-02-27 Finished board rev 0.1
    [breakout_slime.kicad_pcb, breakout_slime.kicad_sch]
2022-02-27 Generated Gerbers
    [breakout_slime-B_Cu.gbl, breakout_slime-B_Mask.gbs, breakout_slime-B_Paste.gbp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]
2022-03-01 Started esp32c3_slime
    [esp32c3_slime.kicad_pcb, esp32c3_slime.kicad_sch]
2022-03-02 Switched charger to TP4056
    [esp32c3_slime.kicad_pcb, esp32c3_slime.kicad_sch]
2022-03-03 Switched power system to M3406
    [esp32c3_slime.kicad_sch]
2022-03-04 Renamed to ferrous_slime, fixed USBC, removed headers
    [esp32c3_slime.kicad_pcb, esp32c3_slime.kicad_sch, ferrous_slime.kicad_pcb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]
2022-03-05 Added IMUs and resolved ERC
    [ferrous_slime.kicad_sch]
2022-03-05 Plotted schematic
    [ferrous_slime.kicad_sch]
2022-03-05 Removed I2C pullups since they are already in breakouts
    [ferrous_slime.kicad_sch]
2022-03-07 Assigned most footprints
    [ferrous_slime.kicad_sch]
2022-03-07 Assigned remaining footprints, did layout
    [ferrous_slime.kicad_pcb, ferrous_slime.kicad_sch]
2022-03-07 Routed all nets, fixed most of silkscreen
    [ferrous_slime.kicad_pcb, ferrous_slime.kicad_sch]
2022-03-07 Added fab files
    [ferrous_slime-B_Cu.gbr, ferrous_slime-B_Fab.gbr, ferrous_slime-B_Mask.gbr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]
2022-03-07 Fixed battery connector polarity on breakout_slime
    [breakout_slime.kicad_pcb, breakout_slime.kicad_sch]
2022-03-08 Removed gerbers, made some minor tweaks to board layout
    [ferrous_slime-B_Cu.gbr, ferrous_slime-B_Fab.gbr, ferrous_slime-B_Mask.gbr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]
2022-03-10 Optimized signal traces and ground fills
    [ferrous_slime.kicad_pcb]
2022-03-11 Filled in ground planes, updated version number, added Changelog
    [breakout_slime.kicad_pcb, breakout_slime.kicad_sch]
2022-03-13 breakout_slime v0.1.2
    [breakout_slime.kicad_pcb, breakout_slime.kicad_sch, ferrous_slime.kicad_pcb]
2022-03-13 Fixed D1 Mini model and added renders
    [breakout_slime.kicad_pcb]
2022-03-15 Added battery sense to ferrous_slime
    [ferrous_slime.kicad_pcb, ferrous_slime.kicad_sch]
2022-03-15 Added breakouts for remaining unused IO
    [ferrous_slime.kicad_pcb, ferrous_slime.kicad_sch]
2022-03-15 Fixed jumper silkscreens and added double ground plane
    [ferrous_slime.kicad_pcb, ferrous_slime.kicad_sch]
2022-03-15 Annotated pins and added silkscreen art
    [ferrous_slime.kicad_pcb, ferrous_slime.kicad_sch]
2022-03-15 Removed Rust_Board and updated all renders/plots
    [ferrous_slime.kicad_pcb, ferrous_slime.kicad_sch]
2022-03-15 ferrous_slime v0.0.1, generated gerbers
    [ferrous_slime-B_Courtyard.gbr, ferrous_slime-B_Cu.gbl, ferrous_slime-B_Fab.gbr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]
2022-03-17 Added refs to silkscreen
    [ferrous_slime-B_Courtyard.gbr, ferrous_slime-B_Cu.gbl, ferrous_slime-B_Fab.gbr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]
2022-03-17 v0.1.0 board released
    [BOM-ferrous_slime.csv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]
2022-03-17 Add image of PCB layout
2022-04-06 Fixed rev # typo on schematic
    [ferrous_slime.kicad_sch]
2022-04-13 [breakout_slime] Released v0.1.3
    [breakout_slime.kicad_pcb, breakout_slime.kicad_sch]
2022-04-13 [breakout_slime] generated gerbers
    [BOM-breakout_slime.csv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]
2022-04-13 [breakout_slime] Fixed wrong slash type in gerber file path
2022-05-24 [breakout_slime] Fixed symbol/footprint lib paths
    [breakout_slime.kicad_pcb]
2022-05-26 [breakout_slime] Released v0.1.4
    [POS-breakout_slime.csv, breakout_slime-CuBottom.gbr, breakout_slime-CuTop.gbr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]
2022-07-06 Added Cases for the BreakoutSlime PCB (#15)
    * Added Cases for the BreakoutSlime PCB
    * Tweaked PR
    [breakout_slime.3mf, breakout_slime.f3z]
2022-07-11 Added Butter Dish Cases (#18)
    [Butter_Dish.3mf, Butter_Dish_Fusion360.f3z]
2022-09-13 [WIP] ICM-20948 breakout (#19)
    * Add icm20948 breakout
    * Add documentation
    * Update hardware/icm20948-breakout/NOTICE
    [icm20948-breakout-BOM.csv, icm20948-breakout.kicad_pcb, icm20948-breakout.kicad_sch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]
2022-10-11 ferrous_slime: 0.2.0 (#20)
    [BOM-ferrous_slime.csv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]
2022-10-12 ferrous_slime: v0.3.0
    [BOM-ferrous_slime.csv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]
2023-01-11 ferrous_slime v0.4.0 (#21)
    [BOM-ferrous_slime.csv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]
2023-01-15 Added adafruit bno step file
    [ferrous_slime.kicad_pcb]

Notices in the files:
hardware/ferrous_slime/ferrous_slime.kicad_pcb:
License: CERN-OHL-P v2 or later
